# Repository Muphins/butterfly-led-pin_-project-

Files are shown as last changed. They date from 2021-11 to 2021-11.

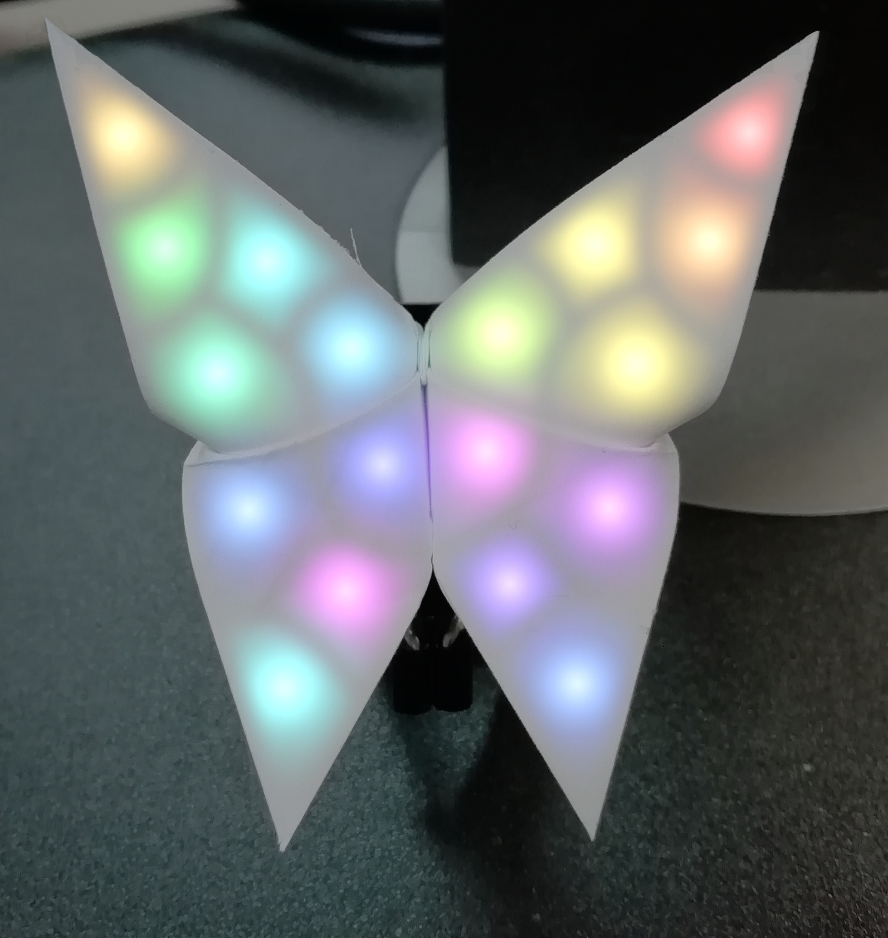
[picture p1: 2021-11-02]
pre-projet/Papillon.jpg

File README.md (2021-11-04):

# butterfly-led-pin Project
Butterfly shaped Hair-pin with RGB LEDs  

This project was born out of the desire to make something special for a gift.

It's a butterfly origami with LEDs stuck under the paper. An accelerometer and microcontroller allow animations that are driven by the head's movements when the pin is worn.  
It is battery powered. The initial goal was to have about 4 hours of autonomy. But with a battery I already had (100mAh) it lasts approximatly 1.5 hour. 
When no movement is detected it transitions itself into sleep mode and can last a little more than a month.

# Sources
All sources are available in this repo. The code is a submodule : https://github.com/Muphins/butterfly-led-pin-code-  

# WIP
## The PCB and its stencil
The PCB and its stencil
  
## Applying the paste
stencil is over PCB  
applying paste  
paste is applied  

[Placing components (youtube)](https://www.youtube.com/watch?v=Wq-hjkRV1W0&list=PLRKnbB8N-SUT_lg6NkQAyX2fzEKrGeBuc&index=2)

## The LEDs
They are RGB addressable LEDs (neopixels).  
They measure 1.5x1.5mm  
LEDs close-up
  
First test to validate I can talk to one LED  
One LED is lit  
Second test with two LEDs and paper to test diffusion  
Two LEDs shine through paper and show different colors

## Sleep mode
[Automaticaly engage sleep mode. Test current consumption (youtube)](https://www.youtube.com/watch?v=bKDfL658R1I&list=PLRKnbB8N-SUT_lg6NkQAyX2fzEKrGeBuc&index=3)  
[Test with battery (youtube)](https://www.youtube.com/watch?v=bKDfL658R1I&list=PLRKnbB8N-SUT_lg6NkQAyX2fzEKrGeBuc&index=3)  

## LEDs layout
Mapping the LEDs on the origami  
LEDs positions marked with pencil on the butterfly's wings  
  
I drew the path for the wires and applied double sided tape  
  
  
And then placed the LEDs. Their pads are oriented to facilitate the wiring  
  
image of the wiring in progress  
  
[Soldering a wire (youtube)](https://www.youtube.com/watch?v=1ZHcxBHy21E&list=PLRKnbB8N-SUT_lg6NkQAyX2fzEKrGeBuc&index=5)  
  
## Final assembly
[Test of all the LEDs before folding (youtube)](https://informotics.fr/images/articles/Papillon/12%20-%20cablage%20wip.jpg)  
During this test I noticed that the double sided tape diffuses the light, showing its shape through the paper:  
we can see a bright square through the paper  
  
Before folding the origami I replaced the small squares by large patches of double sided tape.
  
[This video shows the butterfly folded and battery powered (youtube)](https://www.youtube.com/watch?v=GrwUBladvCI&list=PLRKnbB8N-SUT_lg6NkQAyX2fzEKrGeBuc&index=7)  
[This one shows one of the animations : Starlights (youtube)](https://www.youtube.com/watch?v=PvSEK_88dsE&list=PLRKnbB8N-SUT_lg6NkQAyX2fzEKrGeBuc&index=8)  
[Here the animation shows the accelerometer's X and Y axes (youtube)](https://www.youtube.com/watch?v=w01bJOyoW70&list=PLRKnbB8N-SUT_lg6NkQAyX2fzEKrGeBuc&index=9)

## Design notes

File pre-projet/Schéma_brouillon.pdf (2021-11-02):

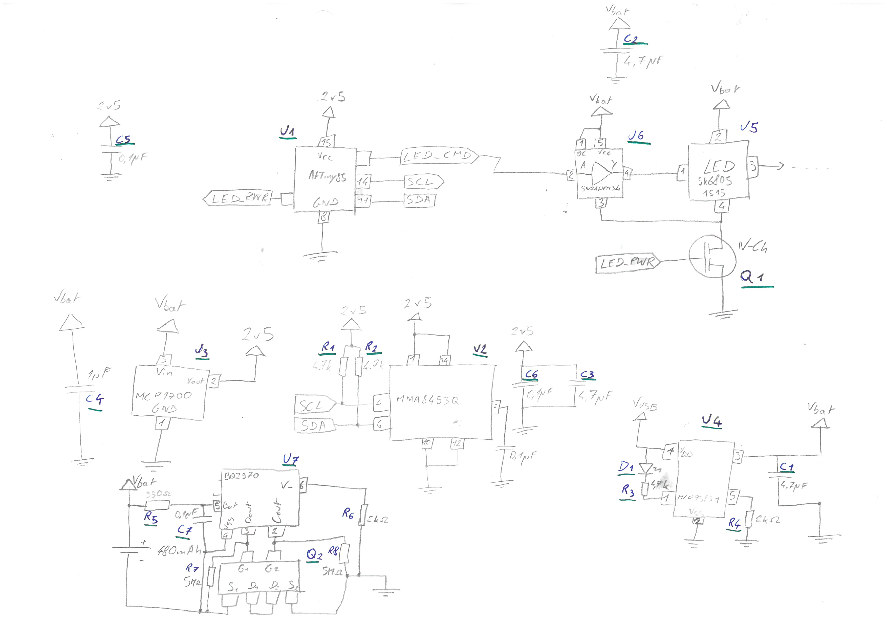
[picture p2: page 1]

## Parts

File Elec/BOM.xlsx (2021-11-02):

Rep | Boitier | Designation | Ref | Code | Fournisseur | Prix | Dx | Dy
U1 | MLF-20 | AtTiny85 | AtTiny85-20MU | 556-ATTINY85-20MU | MOUSER | 0.86 € | 4.0 mm | 4.0 mm
U2 | QFN-16 | Accéléromètre 3-axes i2c | MMA8453QT | 841-MMA8453QT | MOUSER | 2.39 € | 3.0 mm | 3.0 mm
U3 | SOT-23-3 | LDO 2,5v | MCP1700T-2502E/TT | 579-MCP1700T2502E/TT | MOUSER | 0.33 € | 3.0 mm | 3.4 mm
U4 | SOT-23-5 | Chargeur Li-ion 1S | MCP73831T-2ACI/OT | 579-MCP73831T-2ACIOT | MOUSER | 0.50 € | 3.0 mm | 3.4 mm
U5 | 1515 | LED RGB SK6805 |  |  |  | 5.00 € | 1.5 mm | 1.5 mm
U6 | SOT-23-5 | Level-shifter 1-Ch 5.5v | 74LV1T34GWH | 771-74LV1T34GWH | MOUSER | 0.36 € | 3.0 mm | 3.4 mm
~~U7~~ | ~~SOT-23-5~~ | ~~Battery protector~~ | ~~AP9101CAK-BRTRG1~~ | ~~621-AP9101CAK-BRTRG1~~ | ~~MOUSER~~ | ~~0.00 €~~ | ~~3.0 mm~~ | ~~3.4 mm~~
U7 | SOT-23-5 | Battery protector | BQ29707DSER | 595-BQ29707DSER | MOUSER | 0.60 € | 1.5 mm | 1.5 mm
Q1 | SOT-23-3 | MOSFET N-Ch | PMV20XNEAR | 771-PMV20XNEAR | MOUSER | 0.32 € | 3.0 mm | 3.4 mm
Q2 | SOT-23-6 | MOSFET N-Ch double, 100mR | DMN2215UDM-7 | 621-DMN2215UDM-7 | MOUSER | 0.47 € | 3.0 mm | 3.4 mm
C1 | 0805 | 10µF X5R 16v | C0805C106K4PACTU | 1288204 | FARNELL | 0.05 € | 3.0 mm | 1.2 mm
C2 | 0805 | 10µF X5R 16v | C0805C106K4PACTU | 1288204 | FARNELL | 0.05 € | 3.0 mm | 1.2 mm
C3 | 0805 | 10µF X5R 16v | C0805C106K4PACTU | 1288204 | FARNELL | 0.05 € | 3.0 mm | 1.2 mm
C4 | 0402 | 2,2µF X5R 10v | GRM155R61A225KE95D | 2456102 | FARNELL | 0.05 € | 1.7 mm | 0.6 mm
C5 | 0402 | 0,1µF X5R 16v | GRM21BR61E106KA73L | 1735530 | FARNELL | 0.05 € | 1.7 mm | 0.6 mm
C6 | 0402 | 0,1µF X5R 16v | GRM21BR61E106KA73L | 1735530 | FARNELL | 0.05 € | 1.7 mm | 0.6 mm
C7 | 0402 | 0,1µF X5R 16v | GRM21BR61E106KA73L | 1735530 | FARNELL | 0.05 € | 1.7 mm | 0.6 mm
C8 | 0402 | 0,1µF X5R 16v | GRM21BR61E106KA73L | 1735530 | FARNELL | 0.05 € | 1.7 mm | 0.6 mm
R1 | 0402 | DNP! 56kR |  |  |  | 0.05 € | 1.7 mm | 0.6 mm
R2 | 0402 | DNP! 56kR |  |  |  | 0.05 € | 1.7 mm | 0.6 mm
R3 | 0402 | 1kR |  |  |  | 0.05 € | 1.7 mm | 0.6 mm
R4 | 0402 | 2kR |  |  |  | 0.05 € | 1.7 mm | 0.6 mm
R5 | 0402 | 330R |  |  |  | 0.05 € | 1.7 mm | 0.6 mm
R6 | 0402 | 2kR |  |  |  | 0.05 € | 1.7 mm | 0.6 mm
R7 | 0402 | 5MR |  |  |  | 0.05 € | 1.7 mm | 0.6 mm
R8 | 0402 | 5MR |  |  |  | 0.05 € | 1.7 mm | 0.6 mm
D1 | 0603 | LED Ambre | IN-S63AT5A | 743-IN-S63AT5A | MOUSER | 0.33 € | 2.3 mm | 0.8 mm
J1 |  | Embase USB micro-B | 475900101 MOLEX | 538-47590-0001 | MOUSER | 1.46 €
 |  |  |  |  | Total | 13.43 €

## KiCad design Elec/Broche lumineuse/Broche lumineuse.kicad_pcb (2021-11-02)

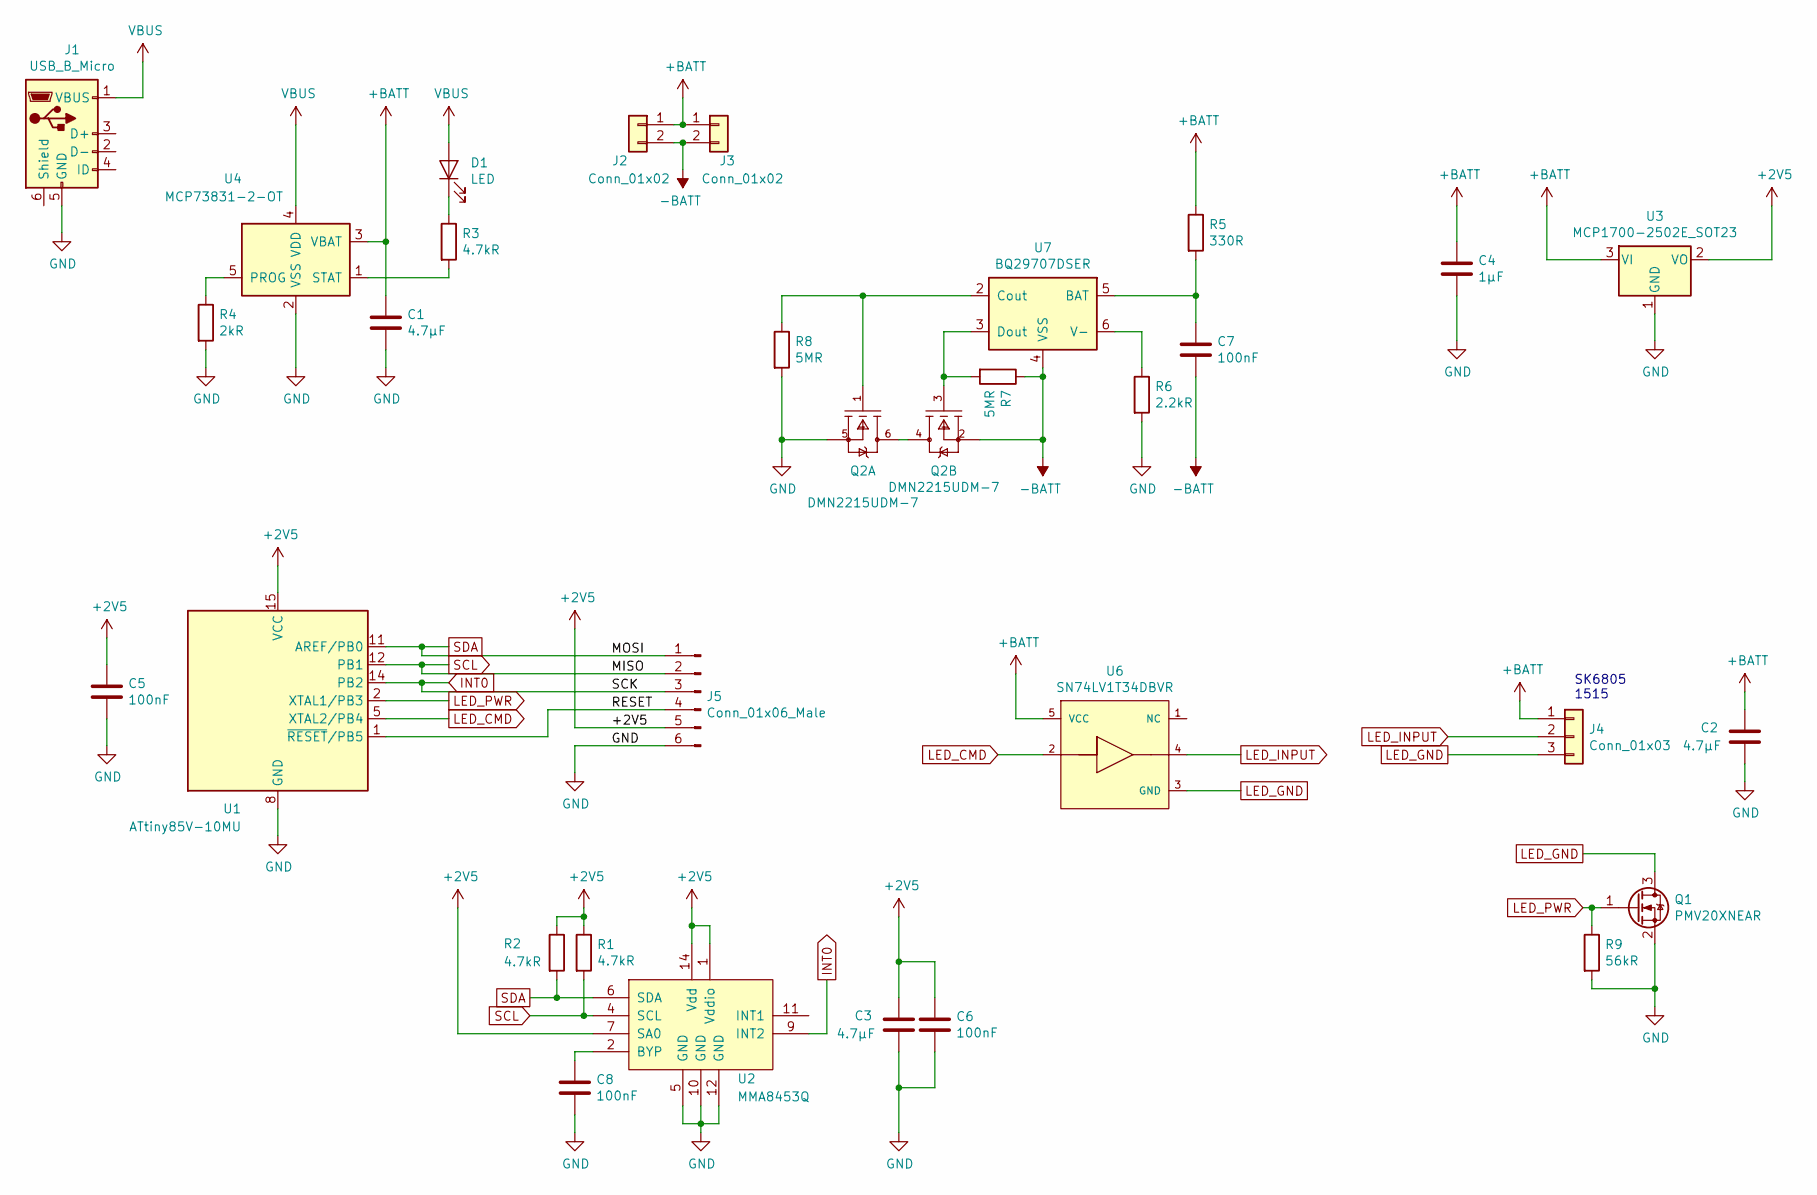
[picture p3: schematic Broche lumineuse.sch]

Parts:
C1, C2, C3: 4.7µF; C_0805_2012Metric
C4: 1µF; C_0402_1005Metric
C5, C6, C7, C8: 100nF; C_0402_1005Metric
D1: LED; D_0603_1608Metric
J1: USB_B_Micro; USB_Micro-AB_Molex_47590-0001
J2, J3: Conn_01x02; PinHeader_1x02_P1.27mm_Vertical
J4: Conn_01x03; PinHeader_1x03_P1.27mm_Vertical
J5: Conn_01x06_Male; JST_SH_SM06B-SRSS-TB_1x06-1MP_P1.00mm_Horizontal
Q1: PMV20XNEAR; SOT-23
Q2: DMN2215UDM-7; SOT-23-6; mouser part number 621-DMN2215UDM-7; digikey description MOSFET 2N-CH 20V 2A SOT-26
R1, R2, R3: 4.7kR; R_0402_1005Metric
R4: 2kR; R_0402_1005Metric
R5: 330R; R_0402_1005Metric
R6: 2.2kR; R_0402_1005Metric
R7, R8: 5MR; R_0402_1005Metric
R9: 56kR; R_0402_1005Metric
U1: ATtiny85V-10MU; QFN-20-1EP_4x4mm_P0.5mm_EP2.6x2.6mm
U2: MMA8453Q; NXP-SOT1676-1-01_2016-B-0
U3: MCP1700-2502E_SOT23; SOT-23
U4: MCP73831-2-OT; SOT-23-5
U6: SN74LV1T34DBVR; SOT-353_SC-70-5; mouser part number 595-SN74LV1T34DBVR; digikey description IC BUF NON-INVERT 5.5V SOT23-5
U7: BQ29707DSER; WSON-6_1.5x1.5mm_P0.5mm

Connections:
+2V5: C3.1, C5.1, C6.1, J5.5, R1.1, R2.1, U1.15 (VCC), U2.1 (Vddio), U2.7 (SA0), U2.14 (Vdd), U3.2 (VO)
+BATT: C1.1, C2.1, C4.1, J2.1, J3.1, J4.1, R5.1, U3.3 (VI), U4.3 (VBAT), U6.5 (VCC)
-BATT: C7.2, J2.2, J3.2, Q2.2 (S2), R7.1, U7.4 (VSS)
/RESET: J5.4, U1.1 (~RESET~/PB5)
GND: C1.2, C2.2, C3.2, C4.2, C5.2, C6.2, C8.2, J1.5 (GND), J5.6, Q1.2 (S), Q2.5 (S1), R4.2, R6.2, R8.2, R9.2, U1.8 (GND), U1.21 (GND), U2.5 (GND), U2.10 (GND), U2.12 (GND), U3.1 (GND), U4.2 (VSS)
INT0: J5.3, U1.14 (PB2), U2.9 (INT2)
LED_CMD: U1.5 (XTAL2/PB4), U6.2 (A)
LED_GND: J4.3, Q1.3 (D), U6.3 (GND)
LED_INPUT: J4.2, U6.4 (Y)
LED_PWR: Q1.1 (G), R9.1, U1.2 (XTAL1/PB3)
unnamed: C7.1, R5.2, U7.5 (BAT)
unnamed: C8.1, U2.2 (BYP)
unnamed: D1.1 (K), R3.1
unnamed: Q2.1 (G1), R8.1, U7.2 (Cout)
unnamed: Q2.3 (G2), R7.2, U7.3 (Dout)
unnamed: Q2.4 (D2), Q2.6 (D1)
unnamed: R3.2, U4.1 (STAT)
unnamed: R4.1, U4.5 (PROG)
unnamed: R6.1, U7.6 (V-)
SCL: J5.2, R1.2, U1.12 (PB1), U2.4 (SCL)
SDA: J5.1, R2.2, U1.11 (AREF/PB0), U2.6 (SDA)
VBUS: D1.2 (A), J1.1 (VBUS), U4.4 (VDD)

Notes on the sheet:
SK6805 1515

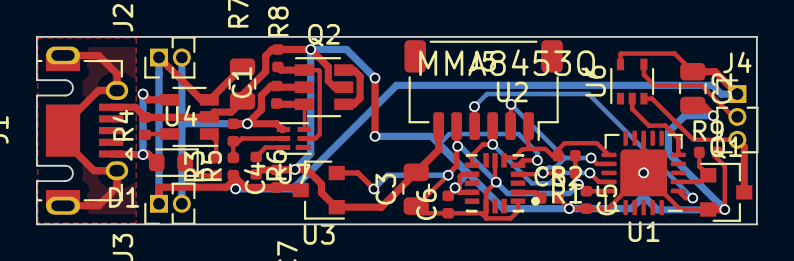
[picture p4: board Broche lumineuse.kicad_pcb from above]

Board: 2 copper layers, 40.0 x 10.4 mm, 31 parts (0 on the bottom side), 22 nets.

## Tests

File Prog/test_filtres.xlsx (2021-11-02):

Impulse | LPF 1 | HPF1 | LPF 2 | HPF 2
0 | 0 | 0 | 0 | 0
0 | 0 | 0 | 0 | 0
0 | 0 | 0 | 0 | 0
0 | 0 | 0 | 0 | 0
0 | 0 | 0 | 0 | 0
0 | 0 | 0 | 0 | 0
0 | 0 | 0 | 0 | 0
0 | 0 | 0 | 0 | 0
0 | 0 | 0 | 0 | 0
0 | 0 | 0 | 0 | 0
0 | 0 | 0 | 0 | 0
0 | 0 | 0 | 0 | 0
0 | 0 | 0 | 0 | 0
0 | 0 | 0 | 0 | 0
0 | 0 | 0 | 0 | 0
0 | 0 | 0 | 0 | 0
0 | 0 | 0 | 0 | 0
0 | 0 | 0 | 0 | 0
0 | 0 | 0 | 0 | 0
0 | 0 | 0 | 0 | 0
0 | 0 | 0 | 0 | 0
0 | 0 | 0 | 0 | 0
0 | 0 | 0 | 0 | 0
0 | 0 | 0 | 0 | 0
0 | 0 | 0 | 0 | 0
0 | 0 | 0 | 0 | 0
0 | 0 | 0 | 0 | 0
0 | 0 | 0 | 0 | 0
0 | 0 | 0 | 0 | 0
0 | 0 | 0 | 0 | 0
0 | 0 | 0 | 0 | 0
0 | 0 | 0 | 0 | 0
0 | 0 | 0 | 0 | 0
0.02 | 0 | 0.02 | 0 | 0
0.04 | 0.000625 | 0.039375 | 0.002857142857 | 0.002232142857
0.06 | 0.001875 | 0.058125 | 0.008571428571 | 0.006696428571
0.08 | 0.00375 | 0.07625 | 0.01714285714 | 0.01339285714
0.1 | 0.00625 | 0.09375 | 0.02857142857 | 0.02232142857
0.12 | 0.009375 | 0.110625 | 0.04285714286 | 0.03348214286
0.14 | 0.013125 | 0.126875 | 0.06 | 0.046875
0.16 | 0.0175 | 0.1425 | 0.08 | 0.0625
0.18 | 0.0225 | 0.1575 | 0.1 | 0.0775
0.2 | 0.028125 | 0.171875 | 0.12 | 0.091875
0.22 | 0.034375 | 0.185625 | 0.14 | 0.105625
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

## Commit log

2021-11-02 rev.1 hardware
    [BOM.xlsx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]
2021-11-02 Maj schéma suivant tests sur rev.1; Maj temporaire du PCB
    [Broche lumineuse.kicad_pcb, Broche lumineuse.sch]
2021-11-02 Test de filtre passe-bas à base de moyenne
    [test_filtres.xlsx]
